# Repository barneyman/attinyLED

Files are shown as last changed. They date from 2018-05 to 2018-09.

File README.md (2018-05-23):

# attinyLED
ws2812B I2C driver using attiny85.

The tiny85 is now an I2C slave that can drive a string of ws2812B leds.

There are two builds - Palette and non-Palette.

The latter will let you control ~90 LEDs, and set RGB for each one, while the former allows you to address ~300 of 
them using a pre-defined palette (basically the web pallete) - there are 8 user palettes available.

There's also a rudimentary macro capability, and it will also run the macro on a PCint.

This project uses my fork of TinyWire (to bubble the PCINT up) - the example app ( https://github.com/barneyman/espMaster )
can be used as a template to drive it - there is a library (ATleds) in https://github.com/barneyman/myLibraries that will 
drive the I2C from a master

The project also includes the eagle and gerber files for the board
The board was produced by ALLPCB for US$15 for 5

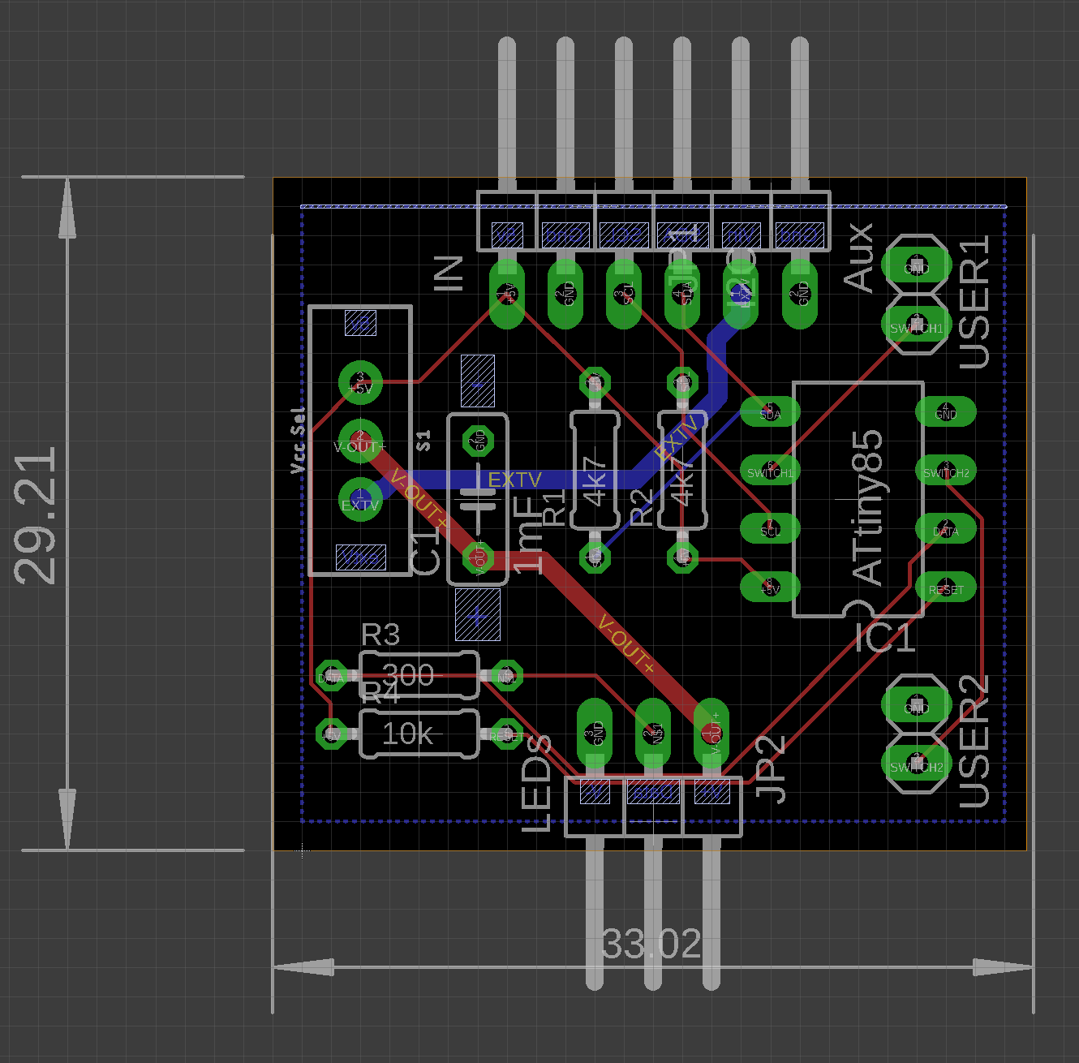
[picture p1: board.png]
Board - Eagle


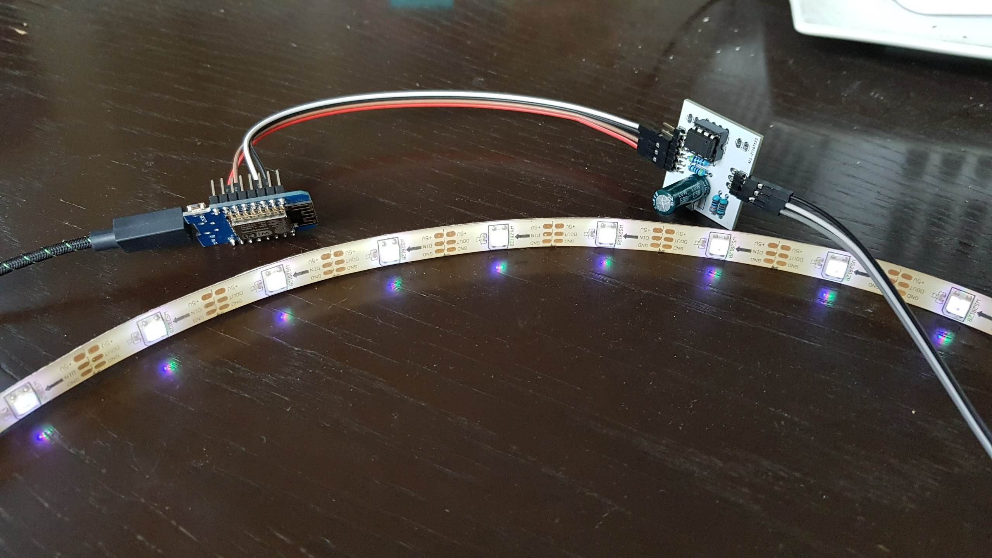
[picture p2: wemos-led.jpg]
Wemos driving board driving 15 leds


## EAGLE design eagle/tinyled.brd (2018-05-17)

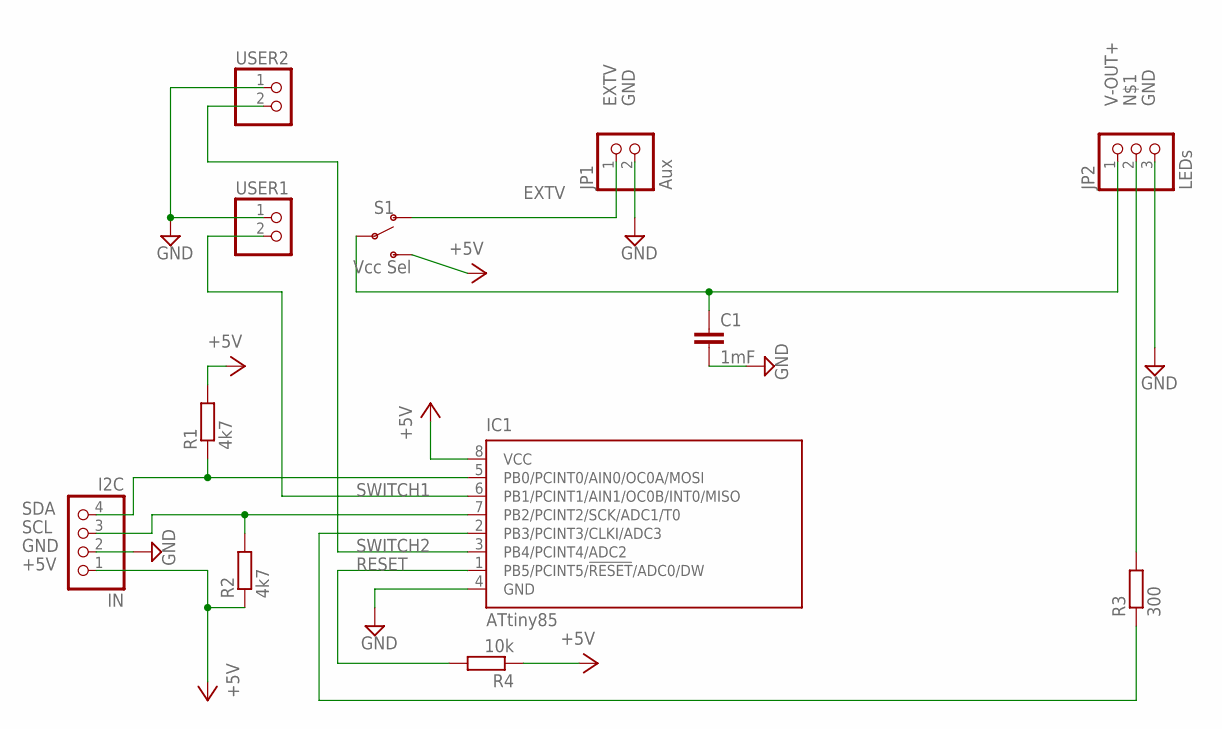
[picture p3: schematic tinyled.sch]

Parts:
C1: 1mF; C050-025X075
IC1: ATtiny85; DIL08
IN: I2C; 1X04/90
JP1: Aux; 1X02/90
JP2: LEDs; 1X03/90
R1, R2: 4k7; 0204/7
R3: 300; 0204/7
R4: 10k; 0204/7
S1: Vcc Sel; SWITCH_SPDT_PTH_11.6X4.0MM
USER1, USER2: PINHD-1X2; 1X02

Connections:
+5V: IC1.8 (VCC), IN.1, R1.2, R2.1, R4.1, S1.3 (S)
DATA: IC1.2 (PB3/PCINT3/CLKI/ADC3), R3.1
EXTV: JP1.1, S1.1 (O)
GND: C1.2, IC1.4 (GND), IN.2, JP1.2, JP2.3, USER1.1, USER2.1
unnamed: JP2.2, R3.2
RESET: IC1.1 (PB5/PCINT5/!RESET!/ADC0/DW), R4.2
SCL: IC1.7 (PB2/PCINT2/SCK/ADC1/T0), IN.3, R2.2
SDA: IC1.5 (PB0/PCINT0/AIN0/OC0A/MOSI), IN.4, R1.1
SWITCH1: IC1.6 (PB1/PCINT1/AIN1/OC0B/INT0/MISO), USER1.2
SWITCH2: IC1.3 (PB4/PCINT4/ADC2), USER2.2
V-OUT+: C1.1, JP2.1, S1.2

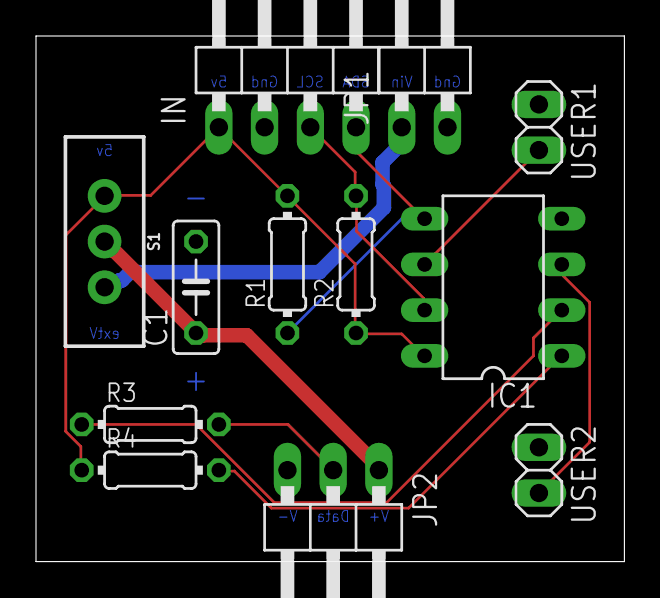
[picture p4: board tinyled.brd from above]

Board: 2 copper layers, 32.7 x 29.2 mm, 12 parts (0 on the bottom side), 11 nets.

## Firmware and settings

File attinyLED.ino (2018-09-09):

#include <TinyWire.h> // https://github.com/lucullusTheOnly/TinyWire.git
#include "light_ws2812.h"
#include "ws2812_config.h"



// define this to use the canned palette = it allows access to more LEDS (because each is referenced by one byte, not 3)
#define _USE_PALETTE

// this enables macro support (you lose some leds)
#define _USE_MACROS

#ifdef _USE_MACROS
#define _RUN_MACRO_ON_BUTTON	PCINT1
#endif

// I2C address used by this chip - feel free to change it 
#define I2C_ADDR	0x10

//#define _XSISTOR_FOR_ON PB1

// for attiny85
#define LED_BUILTIN		PB4
#if !defined(_XSISTOR_FOR_ON) && !defined(_RUN_MACRO_ON_BUTTON)
#define LED_WHITE		PB1
#endif




#ifdef _USE_MACROS
#include <twi.h>
// the max in the TWI code i think, so lets not exceed that
#define MAX_MACRO	TWI_RX_BUFFER_SIZE

#include <circQ.h>

circQueueT<32> macro;
#endif

//circQueueT<8, 3> theQueueTemp;


#ifdef _USE_PALETTE

// YES - these palettes are 4 bytes wide, even tho only 3 are used - it makes the chip math easier in the display functions

uint8_t paletteDiv = 0;

const struct cRGBW ledPalette[] PROGMEM = {
// WARNING - GR Rd Bl !!!!!
	{ 0, 0, 0 },		// black
	{ 255, 255, 255 },	// white
	{ 0,255,0 },		// red
	{ 255,0,  0 },		// lime
	{ 0,0,255 },		// blue
	{ 255,255,0 },		// yellow
	{ 255,0,255 },		// cyan
	{ 0,255,255 },		// magenta
	{ 192,192,192 },	// silver
	{ 128,128,128 },	// grey
	{ 0,128,0 },		// maroon
	{ 128,128,0 },		// olive
	{ 128,0,0 },		// green
	{ 0,128,128 },		// purple
	{ 128,0,128 },		// teal
	{ 0,0,128 }			// navy

};

#define _COLOR_PALLETE_BLACK		0
#define _COLOR_PALLETE_WHITE		1
#define _COLOR_PALLETE_RED			2
#define _COLOR_PALLETE_LIME			3
#define _COLOR_PALLETE_BLUE			4
#define _COLOR_PALLETE_YELLOW		5
#define _COLOR_PALLETE_CYAN			6
#define _COLOR_PALLETE_MAGENTA		7
#define _COLOR_PALLETE_SILVER		8
#define _COLOR_PALLETE_GREY			9
#define _COLOR_PALLETE_MAROON		10
#define _COLOR_PALLETE_OLIVE		11
#define _COLOR_PALLETE_GREEN		12
#define _COLOR_PALLETE_PURPLE		13
#define _COLOR_PALLETE_TEAL			14
#define _COLOR_PALLETE_NAVY			15

#define _COLOR_PALLETE_USER1		16
#define _COLOR_PALLETE_USER2		17
#define _COLOR_PALLETE_USER3		18
#define _COLOR_PALLETE_USER4		19
#define _COLOR_PALLETE_USER5		20
#define _COLOR_PALLETE_USER6		21
#define _COLOR_PALLETE_USER7		22
#define _COLOR_PALLETE_USER8		23

// 5m @ 60pm 
#ifdef _USE_MACROS
#define MAXPIX 256
#else
#define MAXPIX 300
#endif


#define MAX_USER_PALETTE	8
byte led[MAXPIX];
struct cRGBW userPalette[MAX_USER_PALETTE];

#else

// 120 = 2m @60pm or 4 metres @30pm
// 60 = 1m @60pm or 2 metres @30pm
#ifdef _USE_MACROS
#define MAXPIX 80
#else
#define MAXPIX 100
#endif
struct cRGB led[MAXPIX];

#endif



// requestData returned flags
#define _FLAG_ROOM_IN_QUEUE	128
#define _FLAG_QUEUE_FLUSHED	64
#define _FLAG_PALETTE_MODE	32
#define _FLAG_MACROS		16

// sendData commands
#define CMD_RESET	0	// turn it all off
#define CMD_SIZE	1	// actual number of LEDS
#define CMD_SETALL	2	// set all leds to RGB
#define CMD_SETONE	3	// set a single led - offset(0) RGB
#define CMD_SHIFT	4	// shift current set - signed byte (for L and R) RGB replace
#define CMD_ROLL	5	// roll - signed byte
#define CMD_DISPLAY	6	// shunt out to the LEDS - beware, interrupts get cleared, so I2C will fail
#define CMD_INVERT	7	// invert all rgbs
// only works when _XSISTOR_FOR_ON define
#define CMD_ON_OFF		8	// + on/off byte
// palette commands
#define CMD_SETALL_PALETTE		10	// set all leds to RGB
#define CMD_SETONE_PALETTE		11	// set a single led - offset(0) RGB
#define CMD_SHIFT_PALETTE		12	// shift current set - signed byte (for L and R) RGB replace
#define CMD_DIV_PALETTE			13	// apply div to palette colours - one byte = rgb >> div
#define CMD_USER_PALETTE_SET	14	// set one of the user colours - 4 bytes - offset r g b 
// macros
#define CMD_SET_MACRO			15	// len + len bytes
#define CMD_RUN_MACRO			16	// do it
#define CMD_DELAY_MACRO			17	// only honoured in macros, one byte - tenths of seconds
//other 
#define CMD_CHANGE_RESPONSE		18	// what we deliver on a requestData

// how many leds we actually have
unsigned currentCount = MAXPIX;


#ifdef CMD_ROLL
#ifdef _USE_PALETTE
byte roll_led;
#else
struct cRGB roll_led;
#endif
#endif


TinyTwi TinyWire;

#include <avr\power.h>
#include <avr\wdt.h>

// doesnt need to be volatile
//unsigned long displayDuration=0;

// this turns off the delay() timer
// #define _DISABLE_TIMER

// the setup function runs once when you press reset or power the board
void setup() 
{
	// settle down!
	delay(200);

	// power
	ADCSRA &= ~(1 << ADEN); //Disable ADC, saves ~230uA





	// initialize digital pin LED_BUILTIN as an output.
	pinMode(LED_BUILTIN, OUTPUT);
#ifdef _XSISTOR_FOR_ON
#if !defined(_RUN_MACRO_ON_BUTTON)
	pinMode(_XSISTOR_FOR_ON, OUTPUT);
#endif
#else
#endif

	digitalWrite(LED_BUILTIN, LOW);
#ifdef _XSISTOR_FOR_ON
	digitalWrite(_XSISTOR_FOR_ON, LOW);
#else
#if !defined(_RUN_MACRO_ON_BUTTON)
	digitalWrite(LED_WHITE, LOW);
#endif
#endif

	for(int flash=0;flash<3;flash++)
	{
		digitalWrite(LED_BUILTIN, HIGH);
#ifndef _XSISTOR_FOR_ON
#if !defined(_RUN_MACRO_ON_BUTTON)
		digitalWrite(LED_WHITE, HIGH);
#endif
#endif
		delay(100);
		digitalWrite(LED_BUILTIN, LOW);
#ifndef _XSISTOR_FOR_ON
#if !defined(_RUN_MACRO_ON_BUTTON)
		digitalWrite(LED_WHITE, LOW);
#endif
#endif
		delay(200);
	}

#ifdef _DISABLE_TIMER
	// turn timer0 off, it MAY help with the i2c lockups?
	// it may have made a difference ... not convinced
	TCCR0B &= 0B11111000;



#endif


	// turn watchdog off
	MCUSR = 0;
	wdt_disable();

	// clear the LEDS
	memset(&led, 0, sizeof(led));

#ifdef 	_USE_PALETTE
	memset(&userPalette, 0, sizeof(userPalette));
#endif


	// reset effectively
	// and get a timing
	Display();

#ifdef _RUN_MACRO_ON_BUTTON
	// config TinyWire library for I2C slave functionality
	TinyWire.begin(I2C_ADDR, _RUN_MACRO_ON_BUTTON);

	// set direction 0 is input
	DDRB &= ~(1 << _RUN_MACRO_ON_BUTTON);
	// and now it's input, set it as a PULLUP (by writing to it)
	PORTB |= (1 << _RUN_MACRO_ON_BUTTON);
	TinyWire.onISR(ButtonPressed);

#else
	// config TinyWire library for I2C slave functionality
	TinyWire.begin(I2C_ADDR);
	pinMode(LED_WHITE, OUTPUT);
#endif

	// sets callback for the event of a slave receive
	TinyWire.onReceive(onI2CReceive);
	TinyWire.onRequest(onI2CRequest);


}


enum stateMachine {		smIdle=0, smPossibleWork, smSizing, smOnOff,
						smSetAll=10, smSetOne, smShifting, smRolling, smInverting, 
						smSetAllPalette=20, smSetOnePalette, smShiftingPalette, smRollingPalette, smInvertingPalette, smDivPalette, smUserPalette,
						smMacroGetLen=30, smMacroGet, smGetDelayMacro,

						smRequestResponse
				} ;

enum responseStateMachine { rsmFlags=0, rsmStack, rsmDisplayDuration, rsmEoMarkerUNUSED };

volatile stateMachine currentState = stateMachine::smIdle;
volatile responseStateMachine currentRequest = rsmFlags;

// size of the biggest command data (less the command byte)
#define MAX_Q_DATA					4
#define MAX_Q_COMMAND_AND_DATA		(MAX_Q_DATA+1)

unsigned dataCount = 0, dataOutstanding=0;
byte data[MAX_Q_COMMAND_AND_DATA];

#define NEED_DATA(y,x)	{ dataCount=0; dataOutstanding=x; currentState=y; }

bool SumpMacro(byte theByte)
{
	// 
#ifdef _USE_MACROS
	macro.write(theByte);
#endif
	dataCount++;
	return (dataCount == dataOutstanding);
}

bool SumpToNull(byte theByte)
{
	// dev/nul
	dataCount++;
	return (dataCount == dataOutstanding);
}


bool SumpData(byte theByte)
{
	data[dataCount++] = theByte;
	return (dataCount == dataOutstanding);
}



//#define _TRY_SLEEP
#ifdef _TRY_SLEEP
#include <avr/sleep.h>
#endif

#define _CHECK_STACK 128

#ifdef _CHECK_STACK

// defined by GCC
extern uint8_t _end;
extern uint8_t __stack;

#define STACK_CANARY	0xc5

// https://www.nongnu.org/avr-libc/user-manual/mem_sections.html
// USED!!!! is the important attribute here, or the linker hoses it
void StackPaint(void) __attribute__((naked, used, section(".init3")));
void StackPaint(void)
{
	// loops from _end (end of BSS section) to current SP, painting stack canary

	__asm volatile (
		"    ldi r30,lo8(_end)\n"
		"    ldi r31,hi8(_end)\n"
		"    ldi r24,lo8(0xc5)\n" /* STACK_CANARY = 0xc5 */
		"    ldi r25,hi8(__stack)\n"
		"    rjmp .cmp\n"
		".loop:\n"
		"    st Z+,r24\n"
		".cmp:\n"
		"    cpi r30,lo8(__stack)\n"
		"    cpc r31,r25\n"
		"    brlo .loop\n"
		"    breq .loop"::);
}

#define BIZARRE

// walk from end of bss to where the stack has been, max
uint16_t StackRoomCount(void)
{
	const uint8_t *p = &_end;
	const uint8_t *s = &__stack;
	uint16_t       c = 0;

#define _STACK_FIREBREAK_MIN	5

	// start at end of bss walk towards stack
	for (const uint8_t *walker = p; walker < (s - _STACK_FIREBREAK_MIN);walker++)
	{
		if (*walker == STACK_CANARY)
		{
			c++;
		}
		else
		{
			if (c >= _STACK_FIREBREAK_MIN)
				break;
			c = 0;

		}


	}
	return c;
}

#endif




#define _DISPLAY_IN_LOOP
#ifdef _DISPLAY_IN_LOOP
volatile bool displayNow = false;
#endif

#ifdef _USE_MACROS
volatile bool runMacro=false;
#endif

void  loop()
{

	if (currentState == smIdle)
	{
#ifdef _TRY_SLEEP
		// go to sleep
		set_sleep_mode(SLEEP_MODE_PWR_DOWN); // sleep mode is set here
		sleep_enable();
		sleep_mode();                        // System actually sleeps here
		sleep_disable();                     // System continues execution here when watchdog timed out 
#endif
	}

#ifdef _USE_MACROS
	if (runMacro)
	{
		currentState = smPossibleWork;
		macro.popState();
		HandleQueue(runMacro);
		// and display
		Display();
		runMacro = false;
	}
#endif

	// flag set in the recv ISR
	if (displayNow)
	{
		// yield for just a bit, to let i2c finish up, otherwise the cli ruins the ACK response
		//while (TinyWire.slaveReceivng())
			delay(1);

		Display();
		displayNow = false;
	}

}


// called from the OnReceive ISR
void HandleQueue(bool domacro)
{

	// loops, until all received bytes are read
#ifdef _USE_MACROS
	while (domacro?macro.available():TinyWire.available())
#else
	while (TinyWire.available())
#endif
	{
		byte readByte =
#ifdef _USE_MACROS
		(domacro ? macro.read() : TinyWire.read());
#else
		TinyWire.read();
#endif

		switch (currentState)
		{
		case smMacroGet:
			// we cannot do this IN a macro
			if (domacro)
			{
				if (SumpToNull(readByte))
				{
					// go around again
					currentState = smPossibleWork;
				}
			}
			// sumps to a DIFFERENT buffer
			else if (SumpMacro(readByte))
			{
				// go around again
				currentState = smPossibleWork;
#ifdef _USE_MACROS
				// and push the state of the queue - every time we run we pop it back
				macro.pushState();
#endif
			}
			break;
		case smMacroGetLen:
			if (SumpData(readByte))
			{
				// go around again
				NEED_DATA(smMacroGet,data[0]);
			}
			break;
		case smGetDelayMacro:
			if (SumpData(readByte))
			{
				if (domacro)
				{
					delay(data[0] * 100);
				}

				currentState = smPossibleWork;
			}
			break;

		case smRequestResponse:
			if (SumpData(readByte))
			{
				// bounds check
				if((responseStateMachine)data[0]<rsmEoMarkerUNUSED)
					currentRequest = (responseStateMachine)data[0];
				currentState = smPossibleWork;
			}
			break;

		case smOnOff:
			if (SumpData(readByte))
			{
#ifdef _XSISTOR_FOR_ON
				digitalWrite(_XSISTOR_FOR_ON, data[0]?HIGH:LOW);
#endif
				// go around again
				currentState = smPossibleWork;
			}
			break;

		case smDivPalette:
			if (SumpData(readByte))
			{
#ifdef _USE_PALETTE
				paletteDiv = data[0];
				// bounds check
				paletteDiv &= 7;
#endif
				// go around again
				currentState = smPossibleWork;
			}
			break;

		case smUserPalette:
			if (SumpData(readByte))
			{
#ifdef _USE_PALETTE
				int offset = data[0];
				offset -= _COLOR_PALLETE_USER1;

				if (offset < MAX_USER_PALETTE)
				{

					userPalette[offset].r = data[1];
					userPalette[offset].g = data[2];
					userPalette[offset].b = data[3];
				}
#endif
				// go around again
				currentState = smPossibleWork;
			}
			break;

		case smSizing:
			if (SumpData(readByte))
			{
				currentCount = data[0];
				// bounds check
				if (currentCount > MAXPIX)
					currentCount = MAXPIX;

				// go around again
				currentState = smPossibleWork;
			}
			break;
		case smSetAllPalette:
			if (SumpData(readByte))
			{
#ifdef _USE_PALETTE
				for (unsigned each = 0; each < currentCount; each++)
				{
					led[each] = (uint8_t)data[0];
				}
#endif
				// go around again
				currentState = smPossibleWork;
			}
			break;
		case smSetAll:
			if (SumpData(readByte))
			{
#ifndef _USE_PALETTE
				for (unsigned each = 0; each < currentCount; each++)
				{
					led[each].r = (uint8_t)data[0];
					led[each].g = (uint8_t)data[1];
					led[each].b = (uint8_t)data[2];
				}
#endif
				// go around again
				currentState = smPossibleWork;
			}
			break;
		case smSetOnePalette:
			if (SumpData(readByte))
			{
#ifdef _USE_PALETTE
				uint8_t offset = (uint8_t)data[0];
				if (offset < currentCount)
				{
					led[(uint8_t)offset] = (uint8_t)data[1];
				}
#endif
				// go around again
				currentState = smPossibleWork;
			}
			break;
		case smSetOne:
			if (SumpData(readByte))
			{
#ifndef _USE_PALETTE
				uint8_t offset = (uint8_t)data[0];
				if (offset < currentCount)
				{
					led[(uint8_t)offset].r = (uint8_t)data[1];
					led[(uint8_t)offset].g = (uint8_t)data[2];
					led[(uint8_t)offset].b = (uint8_t)data[3];
				}
#endif
				// go around again
				currentState = smPossibleWork;
			}
			break;
		case smRolling:
#ifdef CMD_ROLL
			if (SumpData(readByte))
			{
				int offset = (int)data[0]; // +ve for right, 0 for left
				if (offset)
				{
					// remember the last one 
					roll_led = led[currentCount - 1];
					// move
					memmove(&led[1], &led[0], sizeof(led[1])*(currentCount - 1));
					led[0] = roll_led;
				}
				else
				{
					// remember the first one
					roll_led = led[0];
					memmove(&led[0], &led[1], sizeof(led[1])*(currentCount - 1));
					led[currentCount - 1] = roll_led;
				}
				// go around again
				currentState = smPossibleWork;
			}
#endif
				break;
		case smShiftingPalette:
			if (SumpData(readByte))
			{
#ifdef _USE_PALETTE
				signed char offset = (signed char)data[0];
				// if there's no offset, there's nothing to do!
				if (offset)
				{
					int source = 0, dest = 0, size = currentCount, fillStart;
					if (offset > 0)
					{
						// shift right
						dest += offset;
						fillStart = 0;
					}
					else
					{
						// shift left
						// yes - double negative
						source -= offset;
						fillStart = currentCount + offset;
					}

					size -= abs(offset);

					// shift
					memmove(&led[dest], &led[source], sizeof(led[source])*size);

					// then fill the void ones
					size = abs(offset);

					for (unsigned fill = fillStart; size; size--, fill++)
					{
						led[fill] = (uint8_t)data[1];
					}

				}
#endif
				currentState = smPossibleWork;
			}
			break;

		case smShifting:
			if (SumpData(readByte))
			{
#ifndef _USE_PALETTE
				signed char offset = (signed char)data[0];
				// if there's no offset, there's nothing to do!
				if (offset)
				{
					int source = 0, dest = 0, size = currentCount, fillStart;
					if (offset > 0)
					{
						// shift right
						dest += offset;
						fillStart = 0;
					}
					else
					{
						// shift left
						// yes - double negative
						source -= offset;
						fillStart = currentCount + offset;
					}

					size -= abs(offset);

					// shift
					memmove(&led[dest], &led[source], sizeof(led[source])*size);

					// then fill the void ones
					size = abs(offset);

					for (unsigned fill = fillStart; size; size--, fill++)
					{
						led[fill].r = (uint8_t)data[1];
						led[fill].g = (uint8_t)data[2];
						led[fill].b = (uint8_t)data[3];
					}

				}
#endif
				currentState = smPossibleWork;
			}
			break;
		case smInvertingPalette:
			if (SumpData(readByte))
			{
#ifdef _USE_PALETTE
				// TODO - this doesnt work, logically
				int mask = data[0];
				for (unsigned each = 0; each < currentCount; each++)
				{
					led[each] = (~led[each])&mask;
				}
#endif
				currentState = smPossibleWork;
			}
			break;
		case smInverting:
			if (SumpData(readByte))
			{
#ifndef _USE_PALETTE
				int mask = data[0];
				for (unsigned each = 0; each < currentCount; each++)
				{
					led[each].r = (~led[each].r)&mask;
					led[each].g = (~led[each].g)&mask;
					led[each].b = (~led[each].b)&mask;
				}
#endif
				currentState = smPossibleWork;
			}
			break;
			//case smIdle:
		case smPossibleWork:
			switch (readByte)
			{
			case CMD_RUN_MACRO:
				// we CANNOT do this while we're in macro!
#ifdef _USE_MACROS
				if (!domacro)
				{
					// flag to run in loop()
					runMacro = true;
				}
#endif
				currentState = smPossibleWork;
				break;
			case CMD_DELAY_MACRO:
				NEED_DATA(smGetDelayMacro, 1);
				break;

			case CMD_SET_MACRO:
				// we need the length first
				NEED_DATA(smMacroGetLen, 1);
#ifdef _USE_MACROS
				// and reset the macro queue
				macro.reset();
#endif
				break;

			case CMD_ON_OFF:
				NEED_DATA(smOnOff, 1);
				break;
			case CMD_RESET:
				memset(&led, 0, sizeof(led));
				// state stays the same
				currentState = smPossibleWork;
				break;
			case CMD_DISPLAY:
#ifdef _DISPLAY_IN_LOOP
				if (domacro)
				{
					Display();
				}
				else
				{
					displayNow = true;
				}
#else
				Display();
#endif
				currentState = smPossibleWork;
				break;
			case CMD_CHANGE_RESPONSE:
				NEED_DATA(smRequestResponse, 1);
				break;
			case CMD_SIZE:
				NEED_DATA(smSizing, 1);
				break;
			case CMD_DIV_PALETTE:
				NEED_DATA(smDivPalette, 1);
				break;
			case CMD_SETALL_PALETTE:
				NEED_DATA(smSetAllPalette, 1);
				break;
			case CMD_SETALL:
				NEED_DATA(smSetAll, 3);
				break;
			case CMD_SETONE_PALETTE:
				NEED_DATA(smSetOnePalette, 2);
				break;
			case CMD_SETONE:
				NEED_DATA(smSetOne, 4);
				break;
			case CMD_SHIFT_PALETTE:
				NEED_DATA(smShiftingPalette, 2);
				break;
			case CMD_SHIFT:
				NEED_DATA(smShifting, 4);
				break;
			case CMD_INVERT:
				NEED_DATA(smInverting, 1);
				break;
			case CMD_USER_PALETTE_SET:
				NEED_DATA(smUserPalette, 4);
				break;

#ifdef CMD_ROLL
			case CMD_ROLL:
				NEED_DATA(smRolling, 1);
				break;
#endif
			default:
				break;
			}
			break;
		default:
			break;
		}

		// and breathe
#ifdef _USE_MACROS
		if(runMacro)
			yield();
#endif
	}

	// if we leave the available loop guessing there's more, assume none
	// clear interrupts so the ISR doesn't change this underneath us
	if (currentState == smPossibleWork)
	{ 
		currentState = smIdle;
	}

}



void onI2CReceive(int howMany) 
{
	// we are NOT assured of getting all the bytes in a endTransmission in one chunk
	// so, don't assume we will

	if (currentState == smIdle)
		currentState = smPossibleWork;

	// take as long as you need - no wdt, and nothing else running on the chip
	HandleQueue(false);

}


void onI2CRequest(void)
{
	byte result = currentState;

	switch (currentRequest)
	{
	case rsmEoMarkerUNUSED:
		// never seen
		break;
	case rsmFlags:
		// meh 
		result = currentState;
		// if we have more space left then biggest command + data ..
		//if (TinyWire.available() == theQueueTemp.size())
		{
			result |= _FLAG_QUEUE_FLUSHED;
		}
		//else if (theQueueTemp.space() >= (MAX_Q_COMMAND_AND_DATA))
		{
			result |= _FLAG_ROOM_IN_QUEUE;
		}

#ifdef _USE_PALETTE
		result |= _FLAG_PALETTE_MODE;
#endif

#ifdef _USE_MACROS
		result |= _FLAG_MACROS;
#endif
		break;
	case rsmStack:
#ifdef _CHECK_STACK
		result = StackRoomCount() & 255;
#else
		result = 0;
#endif
		break;
	case rsmDisplayDuration:

		// there's 8bits * 3 colours * num leds * timing
		unsigned long totalTime = 8UL * 3UL * (unsigned long)currentCount * 2UL; // usec
		totalTime /= 1000UL; // msec

		result=(totalTime & 255);

		break;
	}
	TinyWire.send(result);
}

#ifdef _RUN_MACRO_ON_BUTTON
void ButtonPressed(uint8_t pinsChanged)
{
	// us?
	if (pinsChanged & (1 << _RUN_MACRO_ON_BUTTON))
	{
		// if we're aready running, don't bother
		if(!runMacro)
		{
			// if it's low, grounded
			if (!(PINB & (1 << _RUN_MACRO_ON_BUTTON)))
			{
				runMacro = true;
			}
		}
		//digitalWrite(LED_BUILTIN, HIGH);
	}
}
#endif


void Display()
{
#ifndef _USE_PALETTE
	ws2812_setleds(led, currentCount);
#else
	ws2812_sendarray_mask_palette(userPalette, ledPalette, led, currentCount, paletteDiv, _BV(ws2812_pin));
#endif
}

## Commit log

2018-04-21 interrupt driven i2c now
2018-04-21 added invert, and mosly working now
    [attinyLED.ino]
2018-04-24 something goes scatty with i2c 100 or so Display requests in
2018-04-28 fixed the random reset - it appears that I2C recv does not guarantee the whole transmission atom, and it can be delivered in multiples - still a crash after a couple of iterations of the test harness
    [attinyLED.ino]
2018-05-06 disabling timer seems to make it more stable - still crashes - excluding ws2821 code currently
    [attinyLED.ino]
2018-05-06 Display asynch now, out of ISR
    Still a blocking crash in the I2C somewhere
    [attinyLED.ino]
2018-05-14 handle button push
2018-05-15 handle a button being pressed (after changing twi to pass that pcint up)
2018-05-15 added delay command - i've dramtically reduced LED size - i'm getting stack corruption
2018-05-15 added stack checking, reset MAXLEDS to something more appropriate for each build type
    [attinyLED.ino]
2018-05-16 delay before Display seems to fix the I2C race condition (tested with 200 leds)
    [attinyLED.ino]
2018-05-16 added board
    [tinyled.brd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]
2018-05-16 can't use millis() either side of a cli! So, calculate lag
2018-05-17 fixed shiort circuits in design
    [tinyled.brd, tinyled.sch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]

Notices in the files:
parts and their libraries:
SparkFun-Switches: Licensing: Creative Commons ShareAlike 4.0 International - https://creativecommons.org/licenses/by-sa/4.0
